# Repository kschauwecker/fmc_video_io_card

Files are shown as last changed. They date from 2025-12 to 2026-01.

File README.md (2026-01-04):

# FMC Video IO Card
This FMC module features a MIPI Rx and a HDMI Tx interface. It was designed for use with the TEG2000 SOM in combination with the TE0701 carrier by Trenz Electronics, which features a GateMate FPGA by Cologne Chip.

Please see the [blog post on Elektronaut](https://elektronaut.tech/en/fpga/driving-full-hd-video-with-the-cologne-chip-gatemate-fpga/)
for more details on this project.

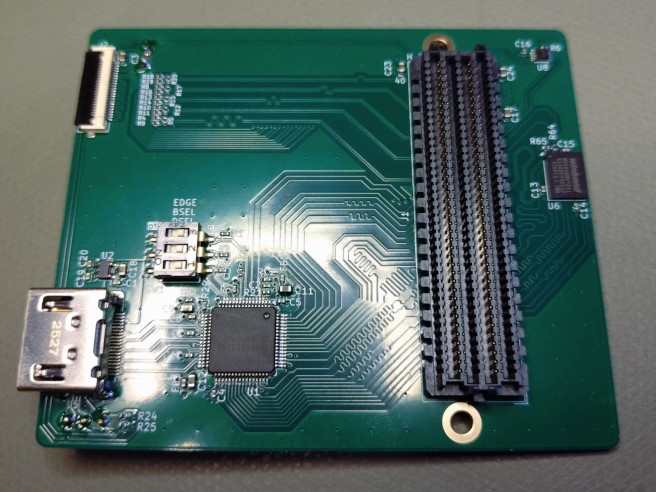
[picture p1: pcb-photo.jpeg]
PCB photo


## Core Features
* The MIPI interface uses a resistor network to connect HS and LP signal to different pins
* For the HDMI interface a parallel RGB converter IC is used (so the FPGA will need to output parallel RGB)
* An additional HyperRAM is provided which can serve as a frame buffer

## Project Status
This is an ongoing project. Only the following hardware parts have been tested and are confirmed to work

* HDMI interface running at 720p @ 60Hz
* HDMI interface running at 1080p @ 60Hz

Test for the MIPI interface and HyperRAM are still pending.

## Known Issues
* The card is a little too large and overlaps slightly with the SOM when mounted on the TE0701 carrier. The standoff screws on the SOM must be removed

## FPGA Software
The FPGA-implementation for the parallel RGB interface is available here:

https://github.com/kschauwecker/gatemate_parallel_rgb

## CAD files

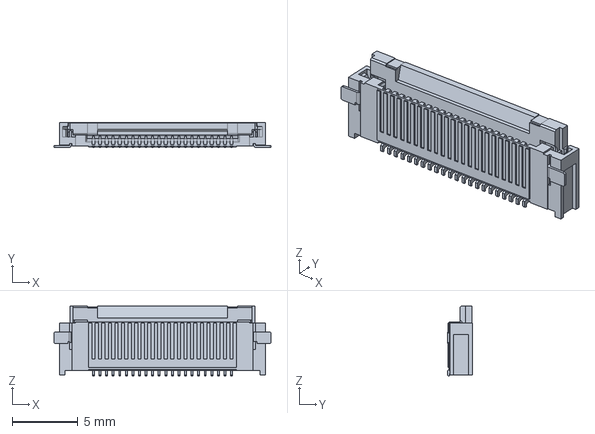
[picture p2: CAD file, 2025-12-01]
3d-models/molex-5051102291.stp
16.5 x 1.90 x 5.30 mm

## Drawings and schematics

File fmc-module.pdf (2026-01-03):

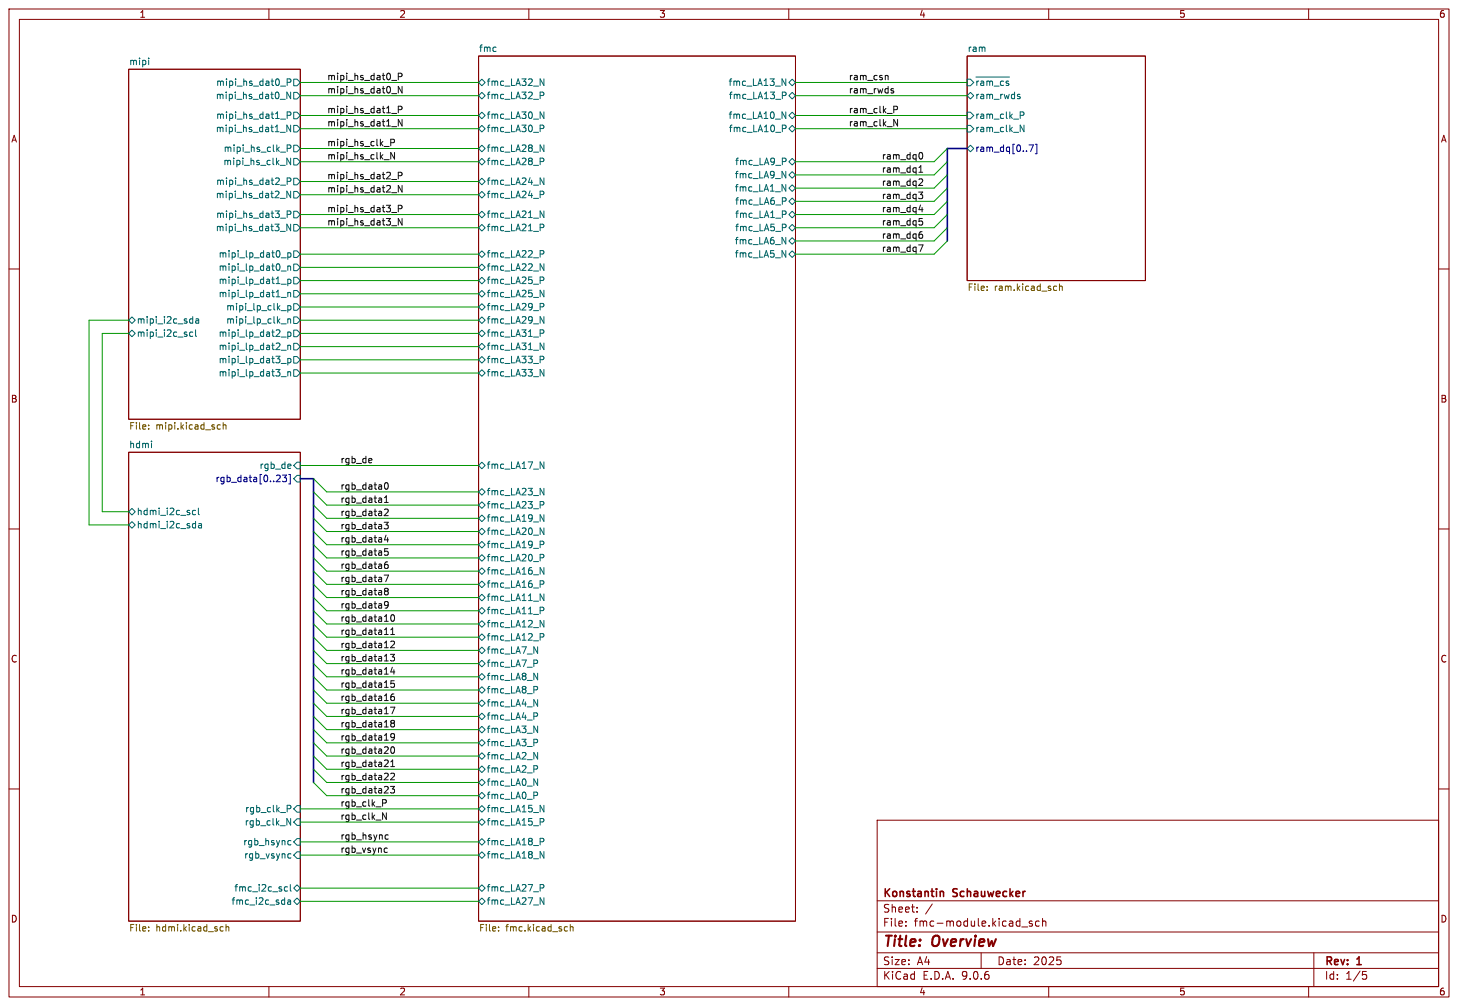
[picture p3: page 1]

File: fmc-module.kicad_sch Sheet: / Konstantin Schauwecker

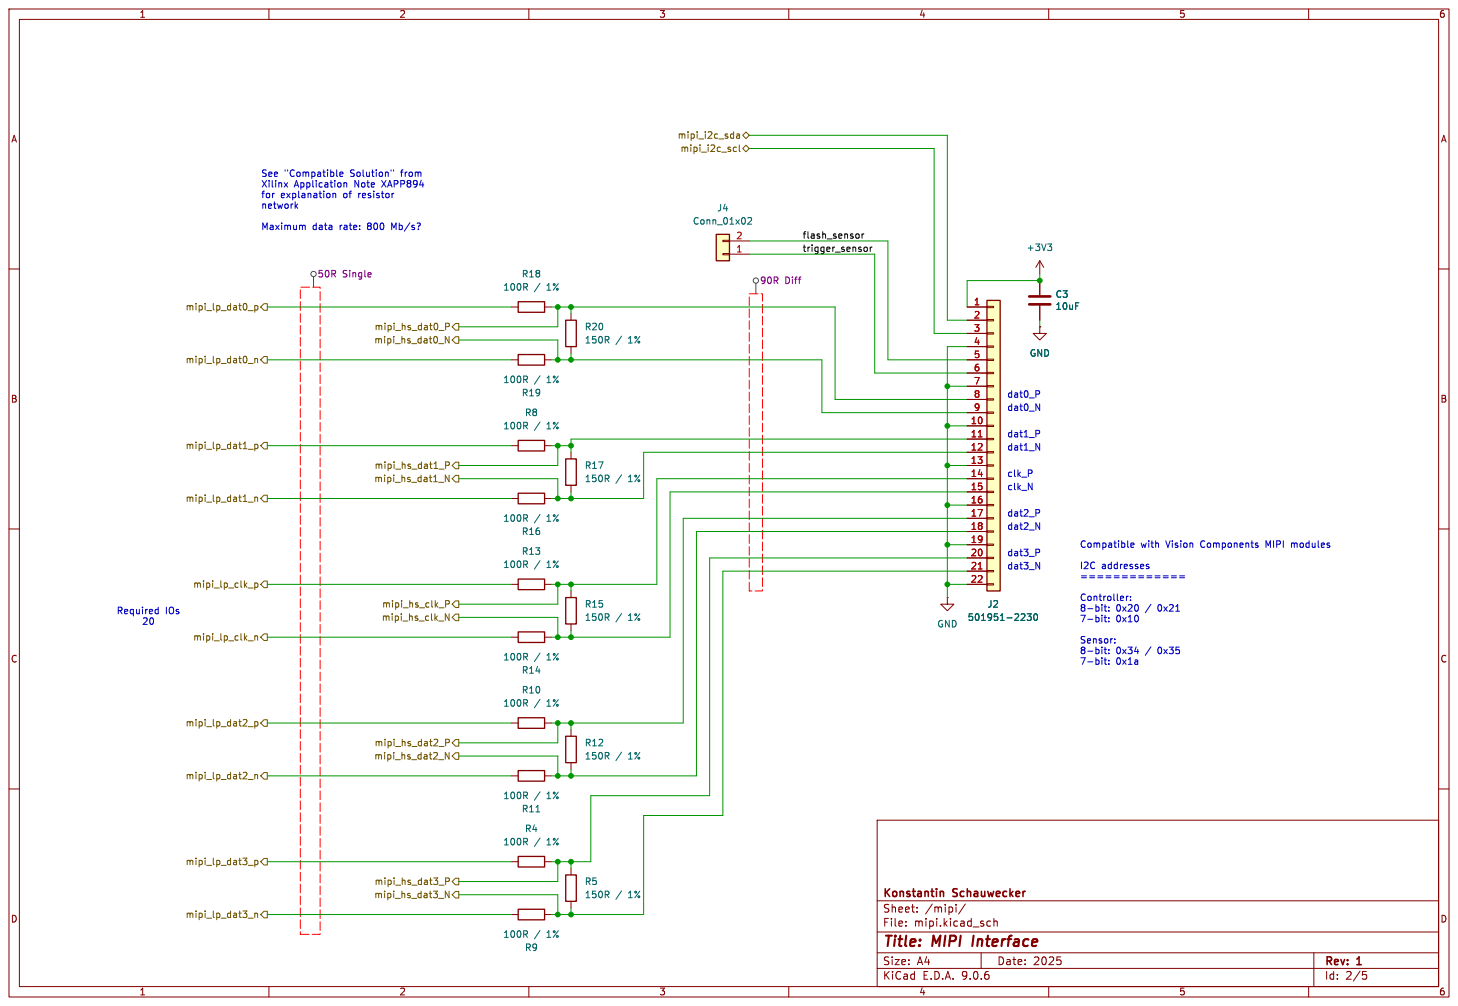
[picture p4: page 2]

Id: 2/5 Title: MIPI Interface

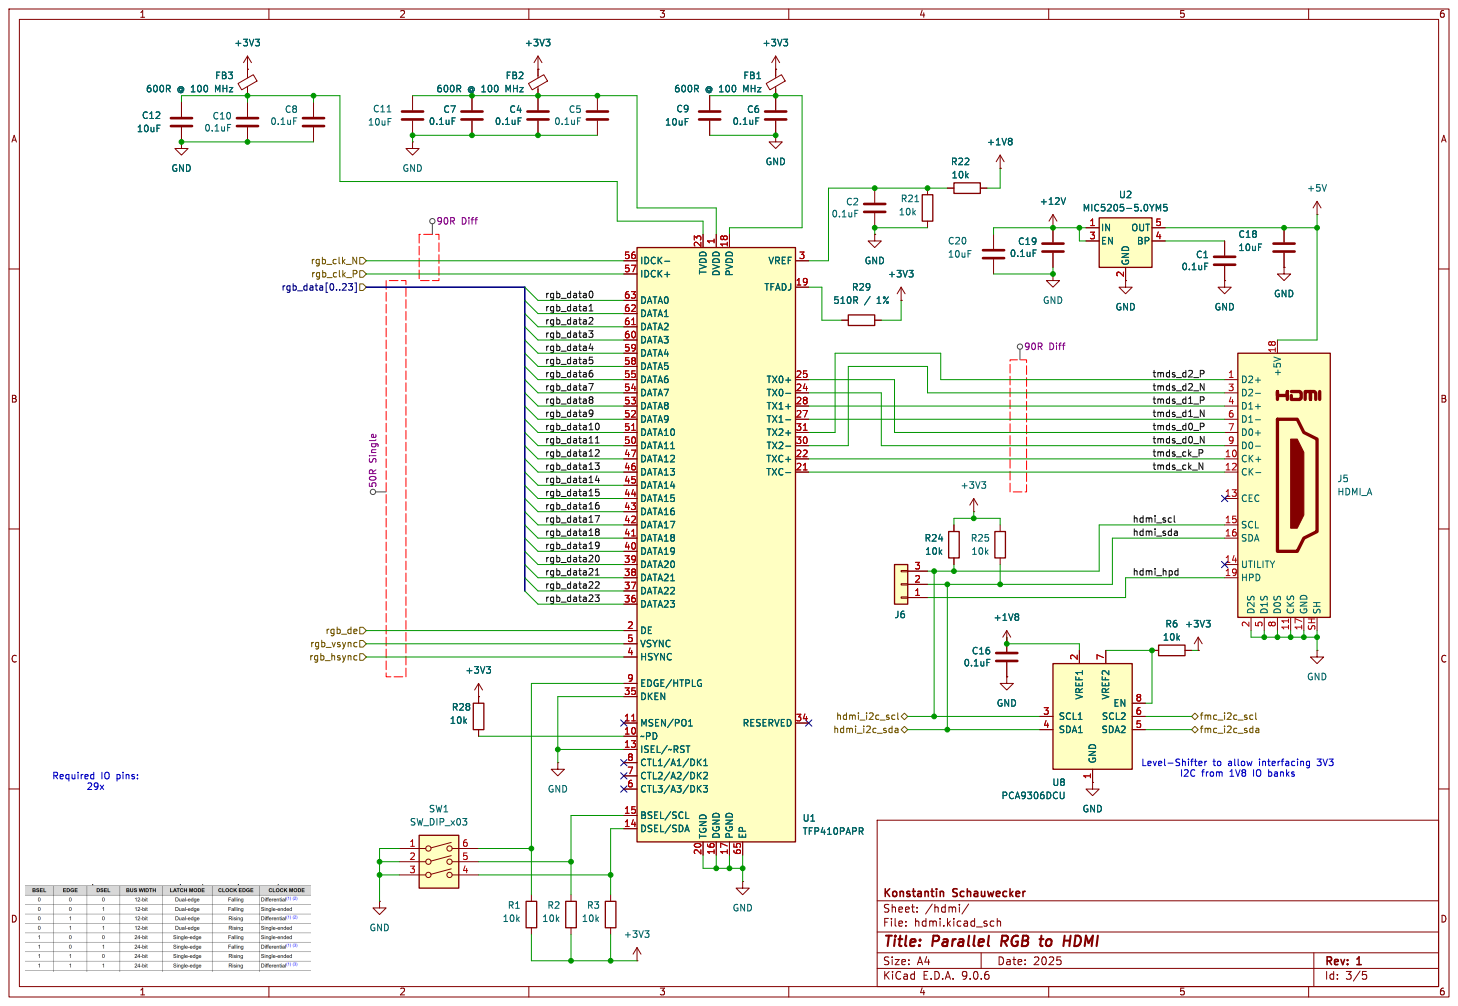
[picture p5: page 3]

1 DGND 16 PVDD 18 PGND 17 EP 65 VREF 3 TFADJ 19 TX0+ 25 TX0- 24 TX1+ 28 TX1- 27 TX2+ 31 TX2- 30 TXC+ 22 TXC- 21 RESERVED 34U1 TFP410PAPR

1 DGND 16 PVDD 18 PGND 17 EP 65 VREF 3 TFADJ 19 TX0+ 25 TX0- 24 TX1+ 28 TX1- 27 TX2+ 31 TX2- 30 TXC+ 22 TXC- 21 RESERVED 34

8 CKS 11 GND 17 SH SH

Id: 3/5 Title: Parallel RGB to HDMI File: hdmi.kicad_sch Sheet: /hdmi/ Konstantin Schauwecker

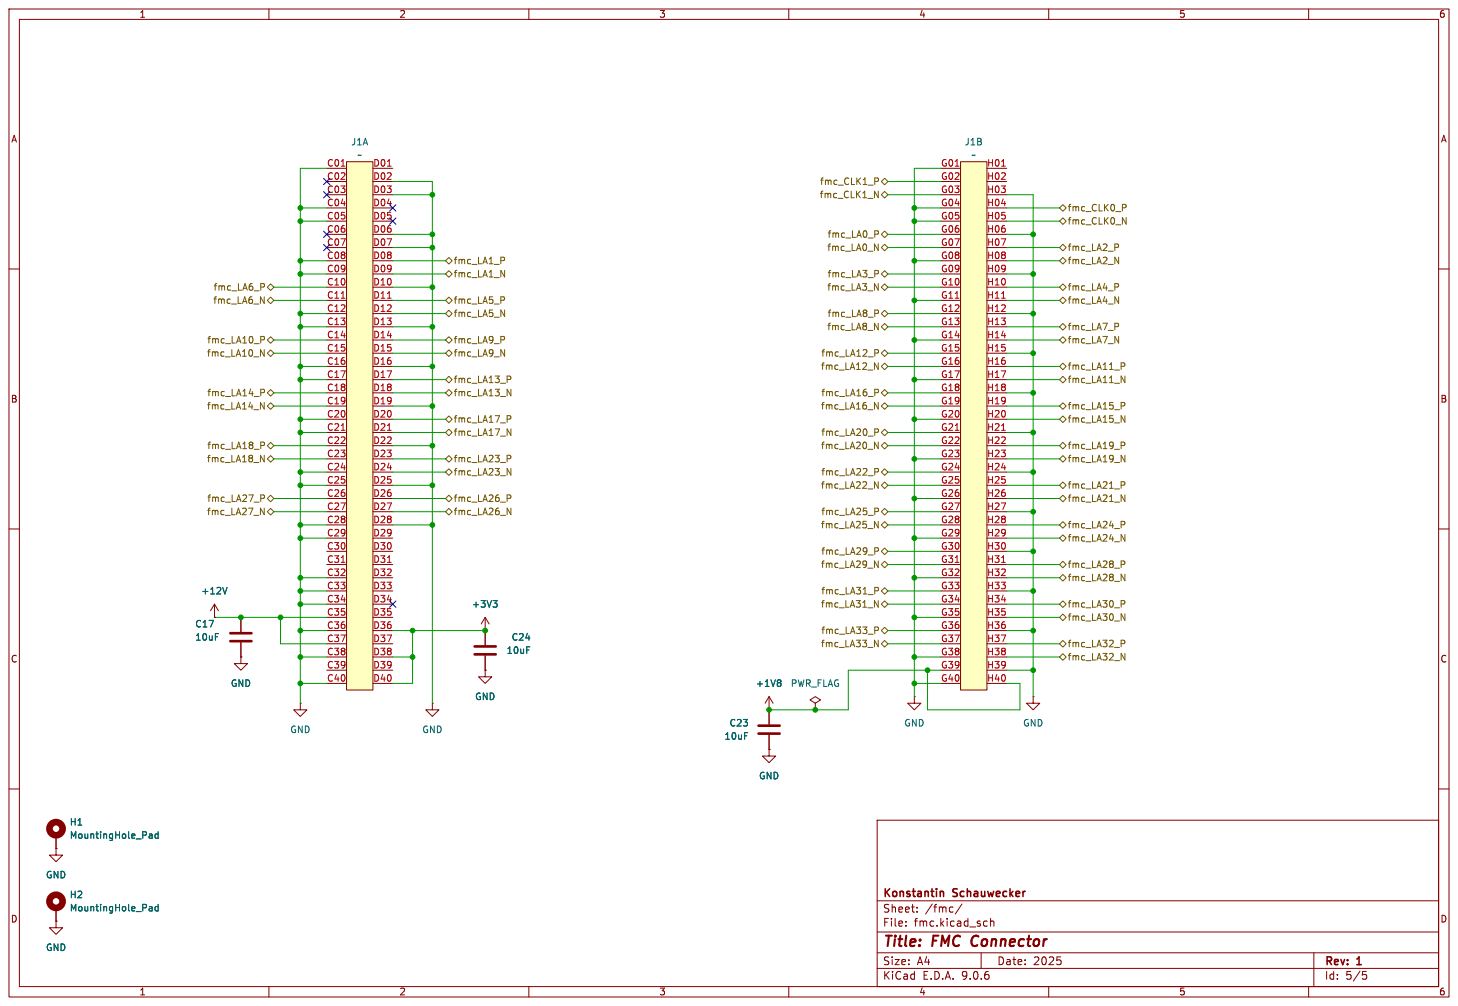
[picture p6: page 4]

Id: 5/5 Title: FMC Connector File: fmc.kicad_sch Sheet: /fmc/ Konstantin SchauweckerGND

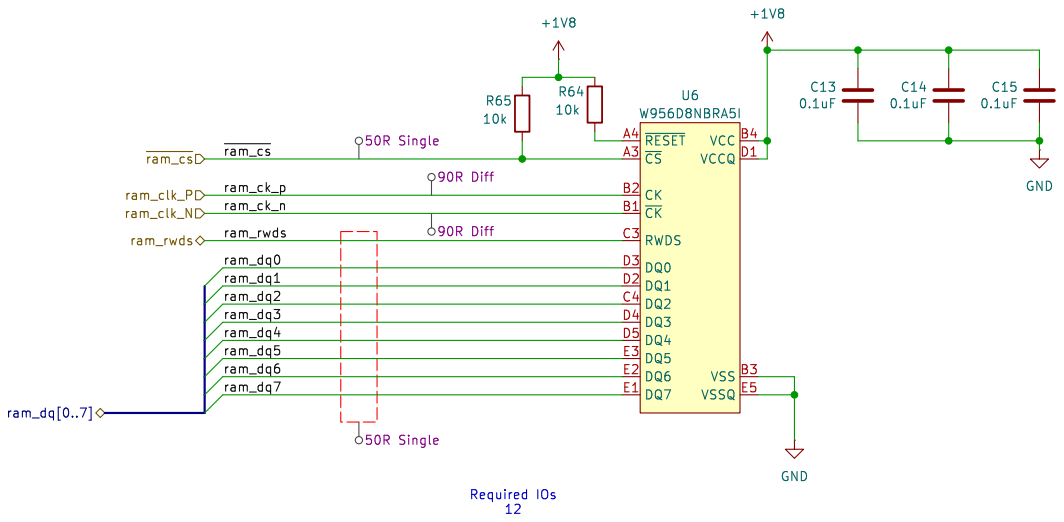
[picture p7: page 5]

File: ram.kicad_sch Sheet: /ram/ Konstantin Schauwecker GND

Id: 6/5 Title: Hyper RAM

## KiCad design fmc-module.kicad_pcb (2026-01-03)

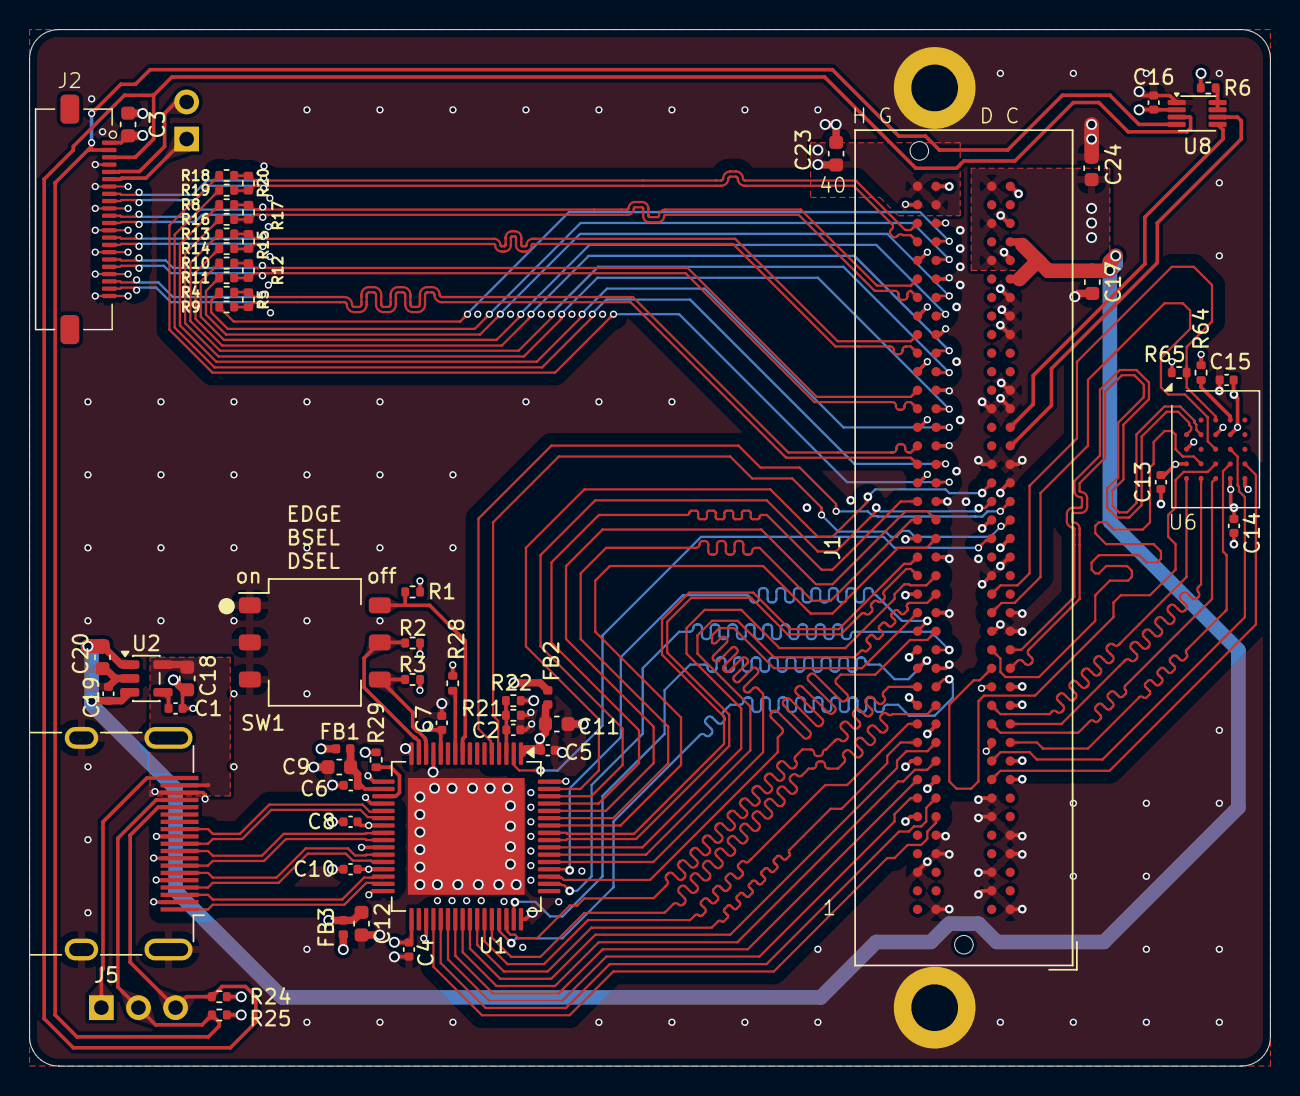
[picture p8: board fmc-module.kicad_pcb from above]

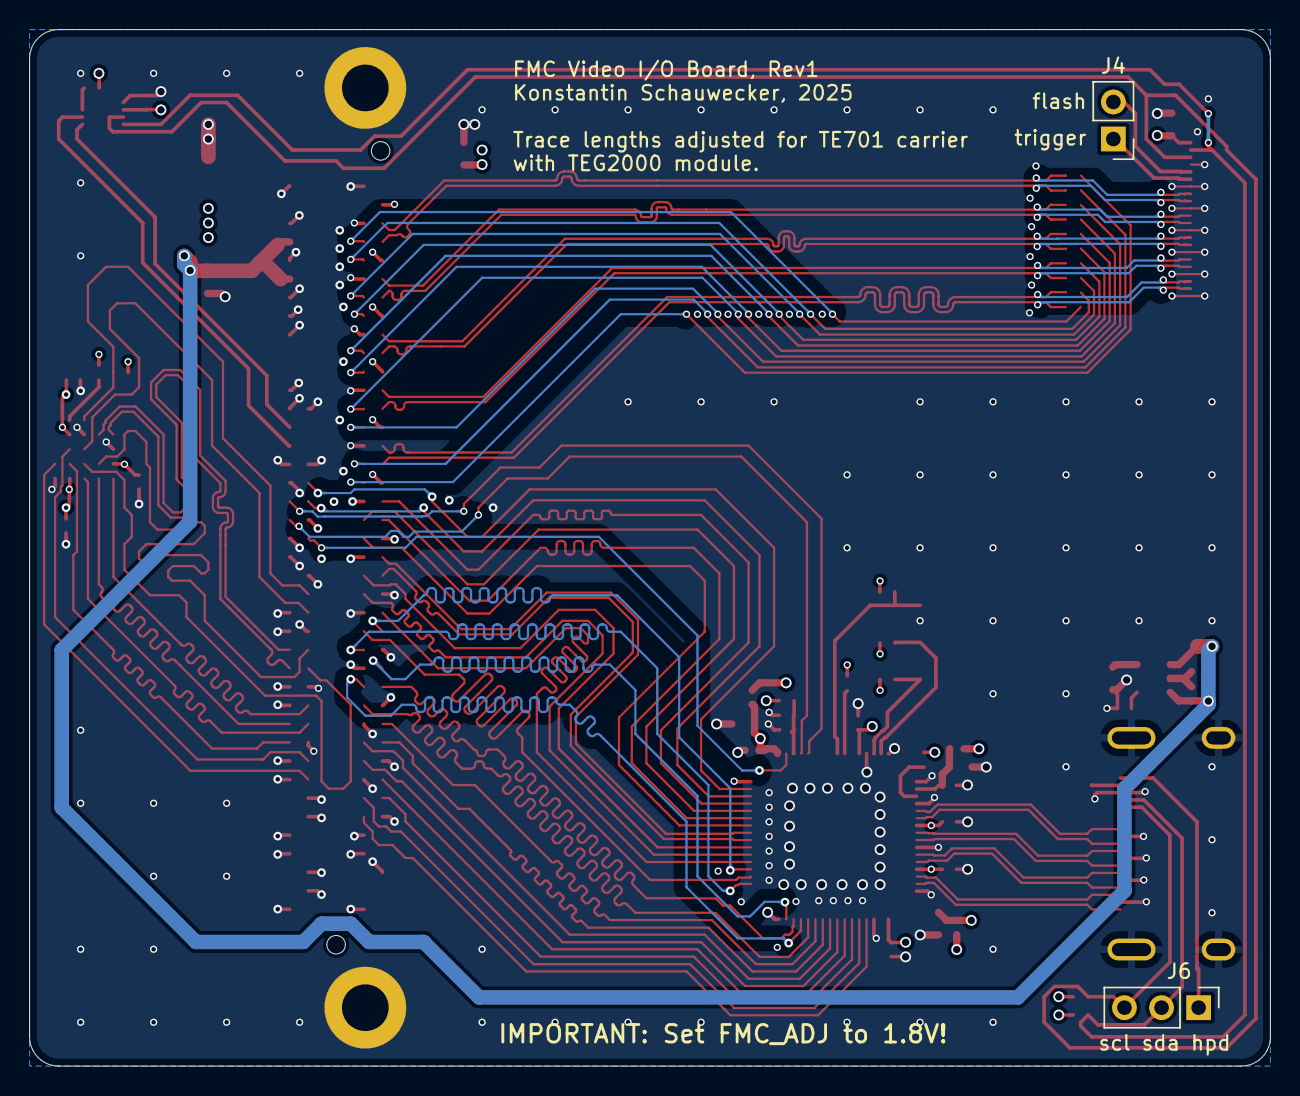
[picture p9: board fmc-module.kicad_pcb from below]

Board: 4 copper layers, 85.0 x 71.0 mm, 64 parts (2 on the bottom side), 93 nets.

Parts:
C1, C2, C4, C5, C6, C7, C8, C10, C13, C14, C15, C16, C19: 0.1uF; C_0402_1005Metric
C3, C9, C11, C12, C17, C18, C20, C23, C24: 10uF; C_0603_1608Metric
FB1, FB2, FB3: 600R @ 100 MHz; L_0402_1005Metric
H1, H2: MountingHole_Pad; MountingHole_3.2mm_M3_DIN965_Pad
J1: Samtec_FMC_ASP-134604-01_4x40_Vertical
J2: 501951-2230; connector-molex-505110-2291
J4: Conn_01x02; PinHeader_1x02_P2.54mm_Vertical
J5: HDMI_A; HDMI_A_Molex_208658-1001_Horizontal
J6: Conn_01x03; PinHeader_1x03_P2.54mm_Vertical
R1, R2, R3, R6, R21, R22, R24, R25, R28, R64, R65: 10k; R_0402_1005Metric
R4, R8, R9, R10, R11, R13, R14, R16, R18, R19: 100R / 1%; R_0402_1005Metric
R5, R12, R15, R17, R20: 150R / 1%; R_0402_1005Metric
R29: 510R / 1%; R_0402_1005Metric
SW1: SW_DIP_x03; SW_DIP_SPSTx03_Slide_Omron_A6S-310x_W8.9mm_P2.54mm
U1: TFP410PAPR; Texas_TQFP-64-1EP_10x10mm_P0.5mm_EP8x8mm_Mask5x5mm
U2: MIC5205-5.0YM5; SOT-23-5
U6: W956D8NBRA5I; hyperram-winbond-8bit
U8: PCA9306DCU; VSSOP-8_2.3x2mm_P0.5mm

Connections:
+1V8: C13.1, C14.1, C15.1, C16.1, C23.1, J1.G39, J1.H40, R22.1, R64.2, R65.2, U6.B4 (VCC), U6.D1 (VCCQ), U6.E4 (VCCQ), U8.2 (VREF1)
+3V3: C3.1, C24.1, FB1.1, FB2.1, FB3.1, J1.D36, J1.D38, J1.D40, J2.1, R1.1, R2.1, R3.1, R6.1, R24.2, R25.2, R28.2, R29.1
+5V: C18.1, J5.18 (+5V), U2.5 (OUT)
+12V: C17.1, C19.1, C20.1, J1.C35, J1.C37, U2.1 (IN), U2.3 (EN)
/fmc/fmc_LA22_N: J1.G25, R19.2
/fmc/fmc_LA22_P: J1.G24, R18.1
/fmc/fmc_LA25_N: J1.G28, R16.2
/fmc/fmc_LA25_P: J1.G27, R8.1
/fmc/fmc_LA27_N: J1.C27, U8.5 (SDA2)
/fmc/fmc_LA27_P: J1.C26, U8.6 (SCL2)
/fmc/fmc_LA29_N: J1.G31, R14.2
/fmc/fmc_LA29_P: J1.G30, R13.1
/fmc/fmc_LA31_N: J1.G34, R11.2
/fmc/fmc_LA31_P: J1.G33, R10.1
/fmc/fmc_LA33_N: J1.G37, R9.2
/fmc/fmc_LA33_P: J1.G36, R4.1
/hdmi/hdmi_hpd: J5.19 (HPD), J6.1
/hdmi/hdmi_scl: J2.3, J5.15 (SCL), J6.3, R24.1, U8.3 (SCL1)
/hdmi/hdmi_sda: J2.2, J5.16 (SDA), J6.2, R25.1, U8.4 (SDA1)
/hdmi/rgb_data0: J1.D24, U1.63 (DATA0)
/hdmi/rgb_data1: J1.D23, U1.62 (DATA1)
/hdmi/rgb_data2: J1.H23, U1.61 (DATA2)
/hdmi/rgb_data3: J1.G22, U1.60 (DATA3)
/hdmi/rgb_data4: J1.H22, U1.59 (DATA4)
/hdmi/rgb_data5: J1.G21, U1.58 (DATA5)
/hdmi/rgb_data6: J1.G19, U1.55 (DATA6)
/hdmi/rgb_data7: J1.G18, U1.54 (DATA7)
/hdmi/rgb_data8: J1.H17, U1.53 (DATA8)
/hdmi/rgb_data9: J1.H16, U1.52 (DATA9)
/hdmi/rgb_data10: J1.G16, U1.51 (DATA10)
/hdmi/rgb_data11: J1.G15, U1.50 (DATA11)
/hdmi/rgb_data12: J1.H14, U1.47 (DATA12)
/hdmi/rgb_data13: J1.H13, U1.46 (DATA13)
/hdmi/rgb_data14: J1.G13, U1.45 (DATA14)
/hdmi/rgb_data15: J1.G12, U1.44 (DATA15)
/hdmi/rgb_data16: J1.H11, U1.43 (DATA16)
/hdmi/rgb_data17: J1.H10, U1.42 (DATA17)
/hdmi/rgb_data18: J1.G10, U1.41 (DATA18)
/hdmi/rgb_data19: J1.G09, U1.40 (DATA19)
/hdmi/rgb_data20: J1.H08, U1.39 (DATA20)
/hdmi/rgb_data21: J1.H07, U1.38 (DATA21)
/hdmi/rgb_data22: J1.G07, U1.37 (DATA22)
/hdmi/rgb_data23: J1.G06, U1.36 (DATA23)
/hdmi/tmds_ck_N: J5.12 (CK-), U1.21 (TXC-)
/hdmi/tmds_ck_P: J5.10 (CK+), U1.22 (TXC+)
/hdmi/tmds_d0_N: J5.9 (D0-), U1.24 (TX0-)
/hdmi/tmds_d0_P: J5.7 (D0+), U1.25 (TX0+)
/hdmi/tmds_d1_N: J5.6 (D1-), U1.27 (TX1-)
/hdmi/tmds_d1_P: J5.4 (D1+), U1.28 (TX1+)
/hdmi/tmds_d2_N: J5.3 (D2-), U1.30 (TX2-)
/hdmi/tmds_d2_P: J5.1 (D2+), U1.31 (TX2+)
/mipi/flash_sensor: J2.5, J4.2
/mipi/trigger_sensor: J2.6, J4.1
/mipi_hs_clk_N: J1.H31, J2.15, R14.1, R15.1
/mipi_hs_clk_P: J1.H32, J2.14, R13.2, R15.2
/mipi_hs_dat0_N: J1.H37, J2.9, R19.1, R20.1
/mipi_hs_dat0_P: J1.H38, J2.8, R18.2, R20.2
/mipi_hs_dat1_N: J1.H34, J2.12, R16.1, R17.1
/mipi_hs_dat1_P: J1.H35, J2.11, R8.2, R17.2
/mipi_hs_dat2_N: J1.H28, J2.18, R11.1, R12.1
/mipi_hs_dat2_P: J1.H29, J2.17, R10.2, R12.2
/mipi_hs_dat3_N: J1.H25, J2.21, R5.1, R9.1
/mipi_hs_dat3_P: J1.H26, J2.20, R4.2, R5.2
/ram/ram_dq0: J1.D14, U6.D3 (DQ0)
/ram/ram_dq1: J1.D15, U6.D2 (DQ1)
/ram/ram_dq2: J1.D09, U6.C4 (DQ2)
/ram/ram_dq3: J1.C10, U6.D4 (DQ3)
/ram/ram_dq4: J1.D08, U6.D5 (DQ4)
/ram/ram_dq5: J1.D11, U6.E3 (DQ5)
/ram/ram_dq6: J1.C11, U6.E2 (DQ6)
/ram/ram_dq7: J1.D12, U6.E1 (DQ7)
/ram_clk_N: J1.C14, U6.B1 (~CK)
/ram_clk_P: J1.C15, U6.B2 (CK)
/ram_csn: J1.D18, R65.1, U6.A3 (~CS)
/ram_rwds: J1.D17, U6.C3 (RWDS)
/rgb_clk_N: J1.H19, U1.56 (IDCK-)
/rgb_clk_P: J1.H20, U1.57 (IDCK+)
/rgb_de: J1.D21, U1.2 (DE)
/rgb_hsync: J1.C22, U1.4 (HSYNC)
/rgb_vsync: J1.C23, U1.5 (VSYNC)
GND: C1.2, C2.2, C3.2, C4.2, C5.2, C6.2, C7.2, C8.2, C9.2, C10.2, C11.2, C12.2, C13.2, C14.2, C15.2, C16.2, C17.2, C18.2, C19.2, C20.2, C23.2, C24.2, H1.1, H2.1, J1.C01, J1.C04, J1.C05, J1.C08, J1.C09, J1.C12, J1.C13, J1.C16, J1.C17, J1.C20, J1.C21, J1.C24, J1.C25, J1.C28, J1.C29, J1.C32, J1.C33, J1.C34, J1.C36, J1.C38, J1.C40, J1.D02, J1.D03, J1.D06, J1.D07, J1.D10, J1.D13, J1.D16, J1.D19, J1.D22, J1.D25, J1.D28, J1.G01, J1.G04, J1.G05, J1.G08, J1.G11, J1.G14, J1.G17, J1.G20, J1.G23, J1.G26, J1.G29, J1.G32, J1.G35, J1.G38, J1.G40, J1.H03, J1.H06, J1.H09, J1.H12, J1.H15, J1.H18, J1.H21, J1.H24, J1.H27, J1.H30, J1.H33, J1.H36, J1.H39, J2.4, J2.7, J2.10, J2.13, J2.16, J2.19, J2.22, J5.2 (D2S), J5.5 (D1S), J5.8 (D0S), J5.11 (CKS), J5.17 (GND), J5.SH, R21.1, SW1.1, SW1.2, SW1.3, U1.13 (ISEL/~RST), U1.16 (DGND), U1.17 (PGND), U1.20 (TGND), U1.26 (TGND), U1.32 (TGND), U1.35 (DKEN), U1.48 (DGND), U1.64 (DGND), U1.65 (EP), U2.2 (GND), U6.B3 (VSS), U6.C1 (VSSQ), U6.E5 (VSSQ), U8.1 (GND)
unnamed: C8.1, C10.1, C12.1, FB3.2, U1.23 (TVDD), U1.29 (TVDD)
unnamed: C4.1, C5.1, C7.1, C11.1, FB2.2, U1.1 (DVDD), U1.12 (DVDD), U1.33 (DVDD)
unnamed: R2.2, SW1.5, U1.15 (BSEL/SCL)
unnamed: R3.2, SW1.4, U1.14 (DSEL/SDA)
unnamed: R1.2, SW1.6, U1.9 (EDGE/HTPLG)
unnamed: C6.1, C9.1, FB1.2, U1.18 (PVDD)
unnamed: R29.2, U1.19 (TFADJ)
unnamed: C2.1, R21.2, R22.2, U1.3 (VREF)
unnamed: R28.1, U1.10 (~PD)
unnamed: C1.1, U2.4 (BP)
unnamed: R64.1, U6.A4 (~RESET)
unnamed: R6.2, U8.7 (VREF2), U8.8 (EN)

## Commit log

2025-12-01 Initial commit of electronics
    [fmc-module.kicad_pcb, fmc-module.kicad_sch, fmc.kicad_sch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]
2025-12-12 Added PCB photo
2026-01-03 Fixed wrong FMC pin labels
    [fmc-module.kicad_pcb, fmc-module.kicad_sch, fmc.kicad_sch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]
